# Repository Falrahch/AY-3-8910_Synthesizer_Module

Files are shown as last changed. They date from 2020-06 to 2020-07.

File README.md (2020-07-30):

# AY-3-8910_Synthesizer_Module

This respository contains all sources needed to create a synthesizer module based on the AY-3-8910 audio chip from General Instruments. The module is based on a ARM Cortex M3: the STM32F103CBT6.
The module is interfaced by a MIDI controller keyboard over a MIDI interface. The output of the module should be fed into an amplifier and can then be played on a speaker.

## Flashing the Module
The PCB has a SWD interface on the three pins on one side of the microcontroller. The controller can be flashed using and ST-Link V2 flasher and OpenOCD (version 0.10.0-13 should work just fine). The configuration-file in "tools" can be used to do so. The name of the binary has to be changed in the file from "AY-3-8910.bin" to the name of the binary that should be flashed. The binary has to be in the same direction as the config-file (OpenOCD/0.10.0-13/scripts). The flashing process is started via a terminal like powershell:

`openocd -f interface/stlink.cfg -f target/stm32f1x.cfg -f flash_stm32f1x.cfg`

It is possible that the flashing won't work the first time and has to be started a second time.

## Adjusting the Clock Frequency
The clock frequency that is sent to the audio chip can be changed in the source code. This will change the tone range of the chip. With a higher clock frequency the range of playable frequencies will shift up. Also, the resolution between the frequencies will get higher.

Acoording to the manufacturer frequencies between 1 MHz and 2 MHz can be used for the chip. However, up to 8 MHz was tested and works fine without audio distortions.

The frequency for the clock is set in *main.cpp* in the function *setupTimer()*. The register values of Timer 3 have to be set by calculating with the CPU frequncy. Since the CPU frequency is 64 MHz and the clock frequency is set to 2 MHz, the auto-reload value is set to 32. To get different frequencies this register and, if necessary, the prescaler register have to be set. The reference manual and tutorials should be consulted if necessary.

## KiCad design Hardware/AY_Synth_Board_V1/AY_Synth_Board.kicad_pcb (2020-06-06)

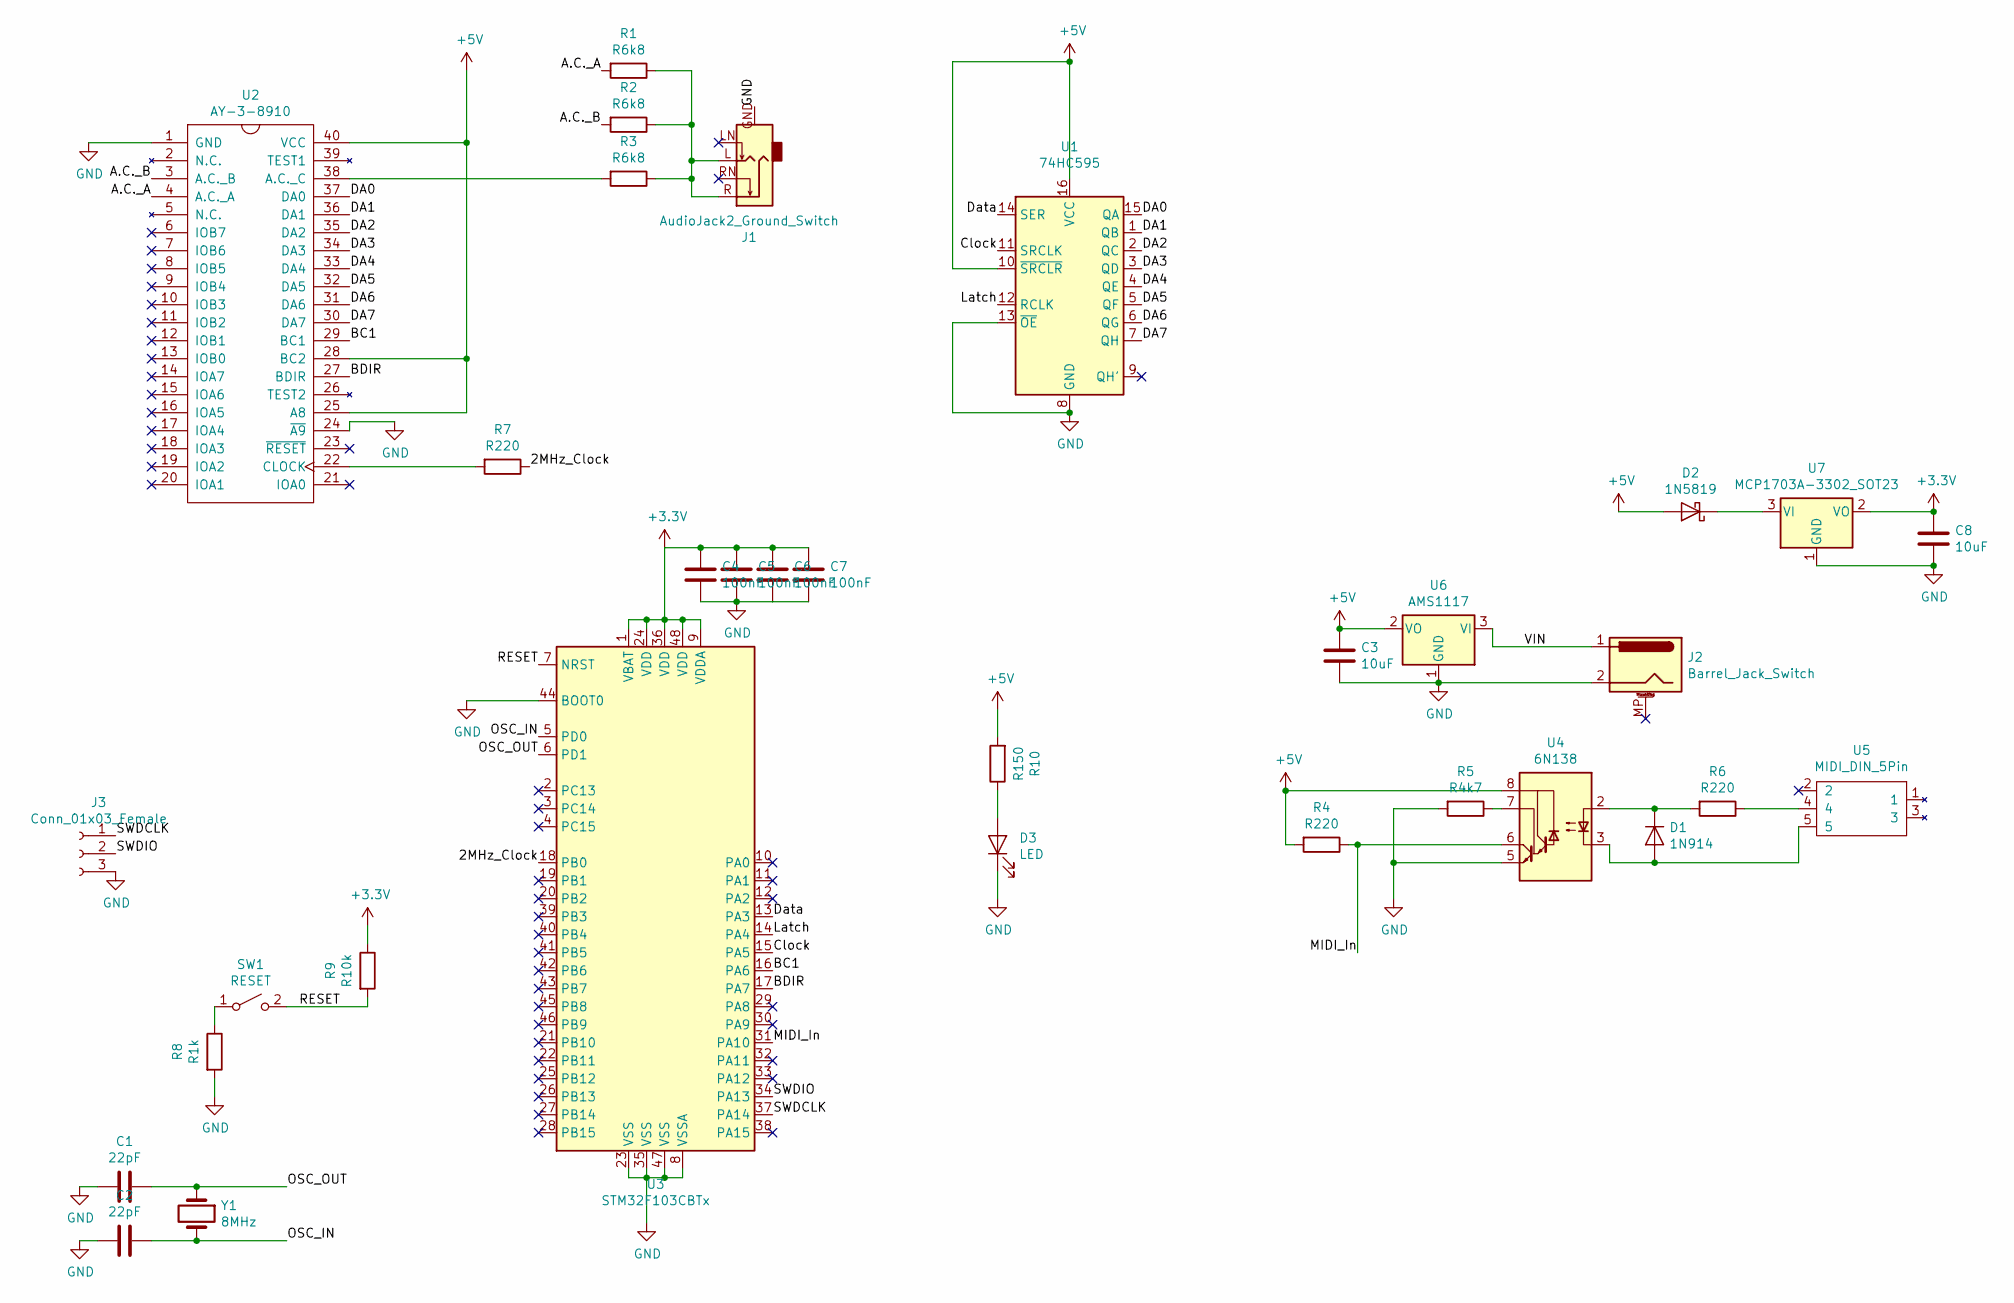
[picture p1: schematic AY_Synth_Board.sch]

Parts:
C1, C2: 22pF; C_1206_3216Metric_Pad1.42x1.75mm_HandSolder
C3, C8: 10uF; C_1206_3216Metric_Pad1.42x1.75mm_HandSolder
C4, C5, C6, C7: 100nF; C_1206_3216Metric_Pad1.42x1.75mm_HandSolder
D1: 1N914; D_1206_3216Metric_Pad1.42x1.75mm_HandSolder
D2: 1N5819; D_SOD-123
D3: LED; LED_1206_3216Metric_Pad1.42x1.75mm_HandSolder
J1: AudioJack2_Ground_Switch; Jack_3.5mm_Ledino_KB3SPRS_Horizontal_Custom
J2: Barrel_Jack_Switch; BarrelJack_Horizontal_MP
J3: Conn_01x03_Female; PinHeader_1x03_P2.54mm_Vertical
R1, R2, R3: R6k8; R_1206_3216Metric_Pad1.42x1.75mm_HandSolder
R4, R6, R7: R220; R_1206_3216Metric_Pad1.42x1.75mm_HandSolder
R5: R4k7; R_1206_3216Metric_Pad1.42x1.75mm_HandSolder
R8: R1k; R_1206_3216Metric_Pad1.42x1.75mm_HandSolder
R9: R10k; R_1206_3216Metric_Pad1.42x1.75mm_HandSolder
R10: R150; R_1206_3216Metric_Pad1.42x1.75mm_HandSolder
SW1: RESET; SW_SPST_TL3305A
U1: 74HC595; DIP-16_W7.62mm_Socket
U2: AY-3-8910; DIP-40_W15.24mm_Socket
U3: STM32F103CBTx; LQFP-48_7x7mm_P0.5mm
U4: 6N138; DIP-8_W7.62mm_Socket
U5: MIDI_DIN_5Pin; din_5_econet_pcb_mount
U6: AMS1117; SOT-223
U7: MCP1703A-3302_SOT23; SOT-23
Y1: 8MHz; Crystal_HC18-U_Vertical

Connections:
+3V3: C4.1, C5.1, C6.1, C7.1, C8.1, R9.1, U3.1 (VBAT), U3.9 (VDDA), U3.24 (VDD), U3.36 (VDD), U3.48 (VDD), U7.2 (VO)
+5V: C3.1, D2.2 (A), R4.2, R10.2, U1.10 (~SRCLR), U1.16 (VCC), U2.25 (A8), U2.28 (BC2), U2.40 (VCC), U4.8 (VCC), U6.2 (VO)
/2MHz_Clock: R7.1, U3.18 (PB0)
/A.C._A: R1.2, U2.4 (A.C._A)
/A.C._B: R2.2, U2.3 (A.C._B)
/BC1: U2.29 (BC1), U3.16 (PA6)
/BDIR: U2.27 (BDIR), U3.17 (PA7)
/Clock: U1.11 (SRCLK), U3.15 (PA5)
/DA0: U1.15 (QA), U2.37 (DA0)
/DA1: U1.1 (QB), U2.36 (DA1)
/DA2: U1.2 (QC), U2.35 (DA2)
/DA3: U1.3 (QD), U2.34 (DA3)
/DA4: U1.4 (QE), U2.33 (DA4)
/DA5: U1.5 (QF), U2.32 (DA5)
/DA6: U1.6 (QG), U2.31 (DA6)
/DA7: U1.7 (QH), U2.30 (DA7)
/Data: U1.14 (SER), U3.13 (PA3)
/Latch: U1.12 (RCLK), U3.14 (PA4)
/MIDI_In: R4.1, U3.31 (PA10), U4.6 (VO2)
/OSC_IN: C2.1, U3.5 (PD0), Y1.2
/OSC_OUT: C1.1, U3.6 (PD1), Y1.1
/RESET: R9.2, SW1.2 (B), U3.7 (NRST)
/SWDCLK: J3.1, U3.37 (PA14)
/SWDIO: J3.2, U3.34 (PA13)
/VIN: J2.1, U6.3 (VI)
GND: C1.2, C2.2, C3.2, C4.2, C5.2, C6.2, C7.2, C8.2, D3.1 (K), J1.GND, J2.2, J3.3, R5.2, R8.2, U1.8 (GND), U1.13 (~OE), U2.1 (GND), U2.24 (~A9), U3.8 (VSSA), U3.23 (VSS), U3.35 (VSS), U3.44 (BOOT0), U3.47 (VSS), U4.5 (GND), U6.1 (GND), U7.1 (GND)
unnamed: D1.1 (K), R6.2, U4.2 (C1)
unnamed: D1.2 (A), U4.3 (C2), U5.5
unnamed: D2.1 (K), U7.3 (VI)
unnamed: D3.2 (A), R10.1
unnamed: J1.L, J1.R, R1.1, R2.1, R3.1
unnamed: R3.2, U2.38 (A.C._C)
unnamed: R5.1, U4.7 (VO1)
unnamed: R6.1, U5.4
unnamed: R7.2, U2.22 (CLOCK)
unnamed: R8.1, SW1.1 (A)

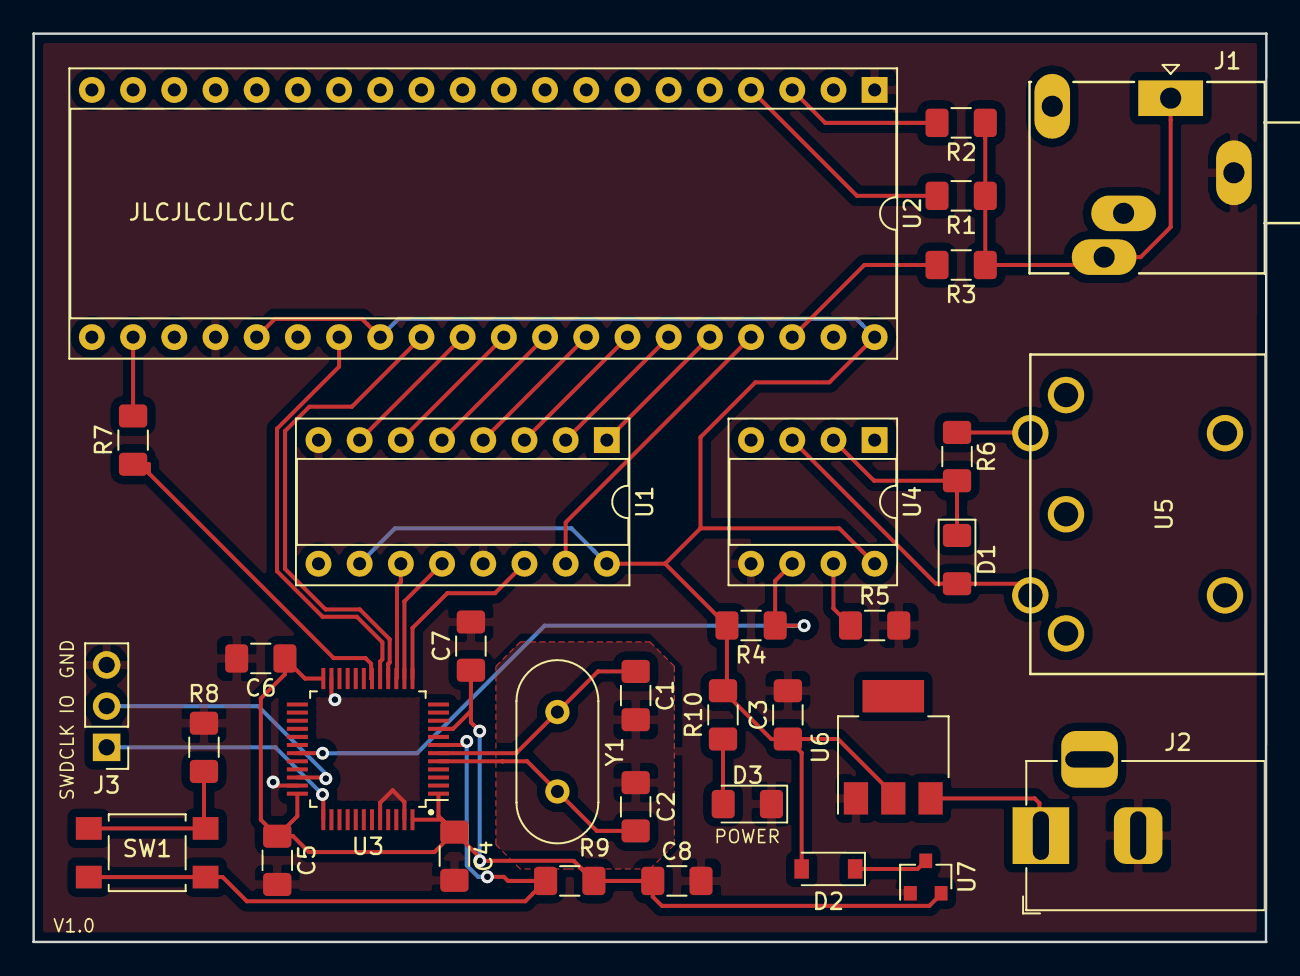
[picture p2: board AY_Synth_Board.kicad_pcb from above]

Board: 2 copper layers, 76.0 x 56.0 mm, 33 parts (0 on the bottom side), 36 nets.

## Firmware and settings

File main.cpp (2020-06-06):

#include "mbed-os/mbed.h"

#include "AY38910.h"
#include "defines.h"
#include "notes.h"

void setupAY38910();
void setupTimer();

uint16_t command = 0;
uint16_t number = 0;
uint16_t speed = 0;

bool newMeasurement = false;

void MIDICallbackHandler();

int main() {
  setupTimer();
  setupAY38910();

  MIDI.attach(&MIDICallbackHandler);

  // uint8 enough?
  uint16_t noteChA = 0;
  uint16_t noteChB = 0;
  uint16_t noteChC = 0;

  while (1) {

    if (newMeasurement) {
      newMeasurement = false;

      if (command == NOTEON) {
        if (number >= 0 && number <= 95 + NOTETABLEOFFSET) {
          if (noteChA == 0) {
            noteChA = number;
            enableChannelA();
            setPeriodeChA(notes[number - NOTETABLEOFFSET]);
          } else if (noteChB == 0) {
            noteChB = number;
            enableChannelB();
            setPeriodeChB(notes[number - NOTETABLEOFFSET]);
          } else if (noteChC == 0) {
            noteChC = number;
            enableChannelC();
            setPeriodeChC(notes[number - NOTETABLEOFFSET]);
          }
        }
      } else if (command == NOTEOFF) {
        if (number == noteChA) {
          noteChA = 0;
          disableChannelA();
        } else if (number == noteChB) {
          noteChB = 0;
          disableChannelB();
        } else if (number == noteChC) {
          noteChC = 0;
          disableChannelC();
        }
      }
    }
  }
}

void setupAY38910() { setMix(true, true, false, false, false, true); }

void setupTimer() {

  RCC->APB2ENR |= RCC_APB2ENR_IOPBEN; // enable port a clock
  RCC->APB1ENR |= RCC_APB1ENR_TIM3EN;

  /*
      Enable alternate function for pin PB0
      The last four bits are for pin 0
      0x9 = 0b1001
          CNF0:   0b10 in output mode: Alternate function output Push-pull
          MODE0:  0b01: Output mode, max speed 10 MHz
   */
  GPIOB->CRL = 0x0000000009;

  /*
      Timer prescaler
   */
  TIM3->PSC = 0;

  /*
      Timer auto-reload value
   */
  TIM3->ARR = 32;

  /*
      Timer Capture/Compare value register
      Determines the dutycycle of the PWM
          when set to half the value of the ARR the dutycycle is 50%
   */
  TIM3->CCR3 = TIM3->ARR / 2;

  /*
      Timer capture/compare mode register
      CCMR2 because channel 3 is part of that
      OC3M: 0b110: PWM mode 1
   */
  TIM3->CCMR2 |= TIM_CCMR2_OC3M_2 | TIM_CCMR2_OC3M_1;

  /*
      Timer event generation register
      UG: 0b1: update generation, reinitializes the counter and generates an
     update of the registers
   */
  TIM3->EGR |= TIM_EGR_UG; // ENABLE update generation

  /*
      Timer capture/compare enable register
      CC3E in output mode: 0b1: Capture/Compare 3 output enable
   */
  TIM3->CCER |= TIM_CCER_CC3E;

  /*
      Timer control register
      CEN: 0b1: counter enable
   */
  TIM3->CR1 |= TIM_CR1_CEN; // ENABLE Timer counter
}

void MIDICallbackHandler() {
  if (MIDI.readable()) {
    command = MIDI.getc();
    number = MIDI.getc();
    speed = MIDI.getc();
    newMeasurement = true;
  }
}

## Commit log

2020-06-06 Inital commit
    [flash_stm32f1x.cfg]
2020-06-06 Commit hardware layout files
    [AY_Synth_Board.kicad_pcb, AY_Synth_Board.sch]
